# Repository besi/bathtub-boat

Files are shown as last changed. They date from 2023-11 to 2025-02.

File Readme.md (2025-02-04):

Bath tub boat
==============

Measure the temperature of your bath tub.
Video: https://vimeo.com/909430078

## Hardware 

### Version 2
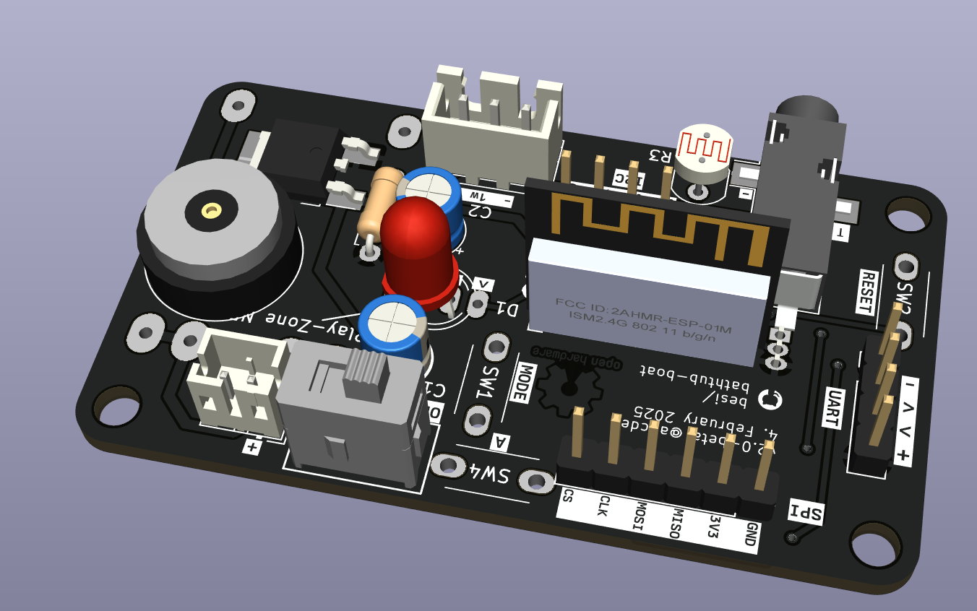
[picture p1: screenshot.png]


### Version 1
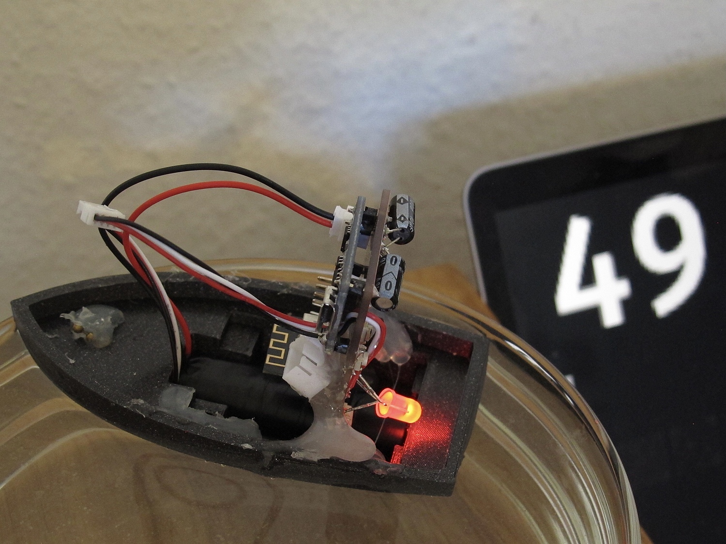
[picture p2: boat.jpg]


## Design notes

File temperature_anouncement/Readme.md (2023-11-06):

# Bathtub Temperature Announcement

- I'm in the kitchen
- The bathtub is filling up
- I'll know when the perfect temperature of 42° is reached

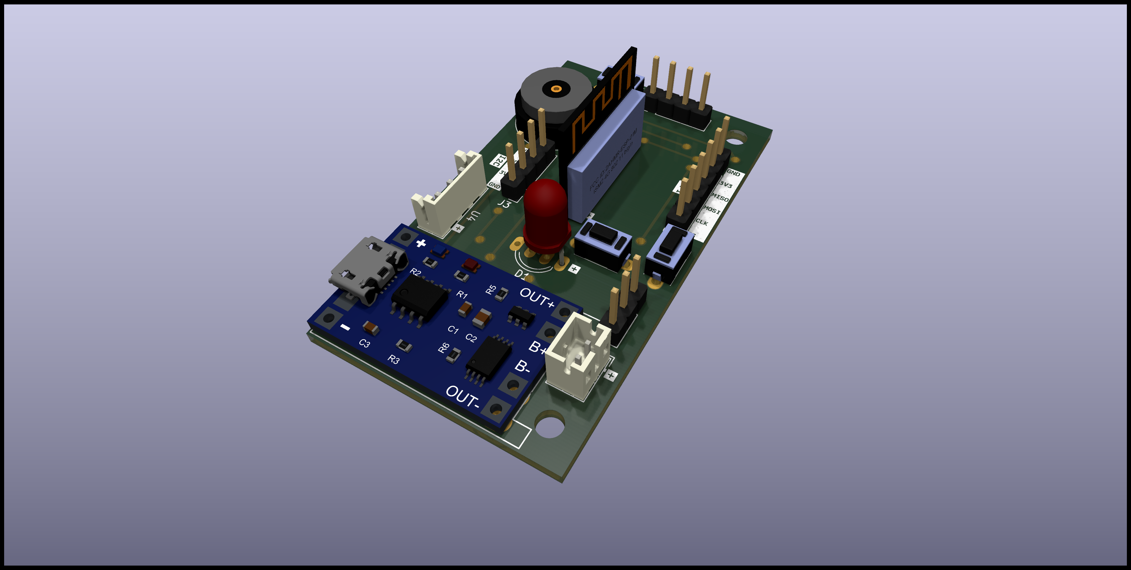
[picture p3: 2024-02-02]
bathtub-boat.png

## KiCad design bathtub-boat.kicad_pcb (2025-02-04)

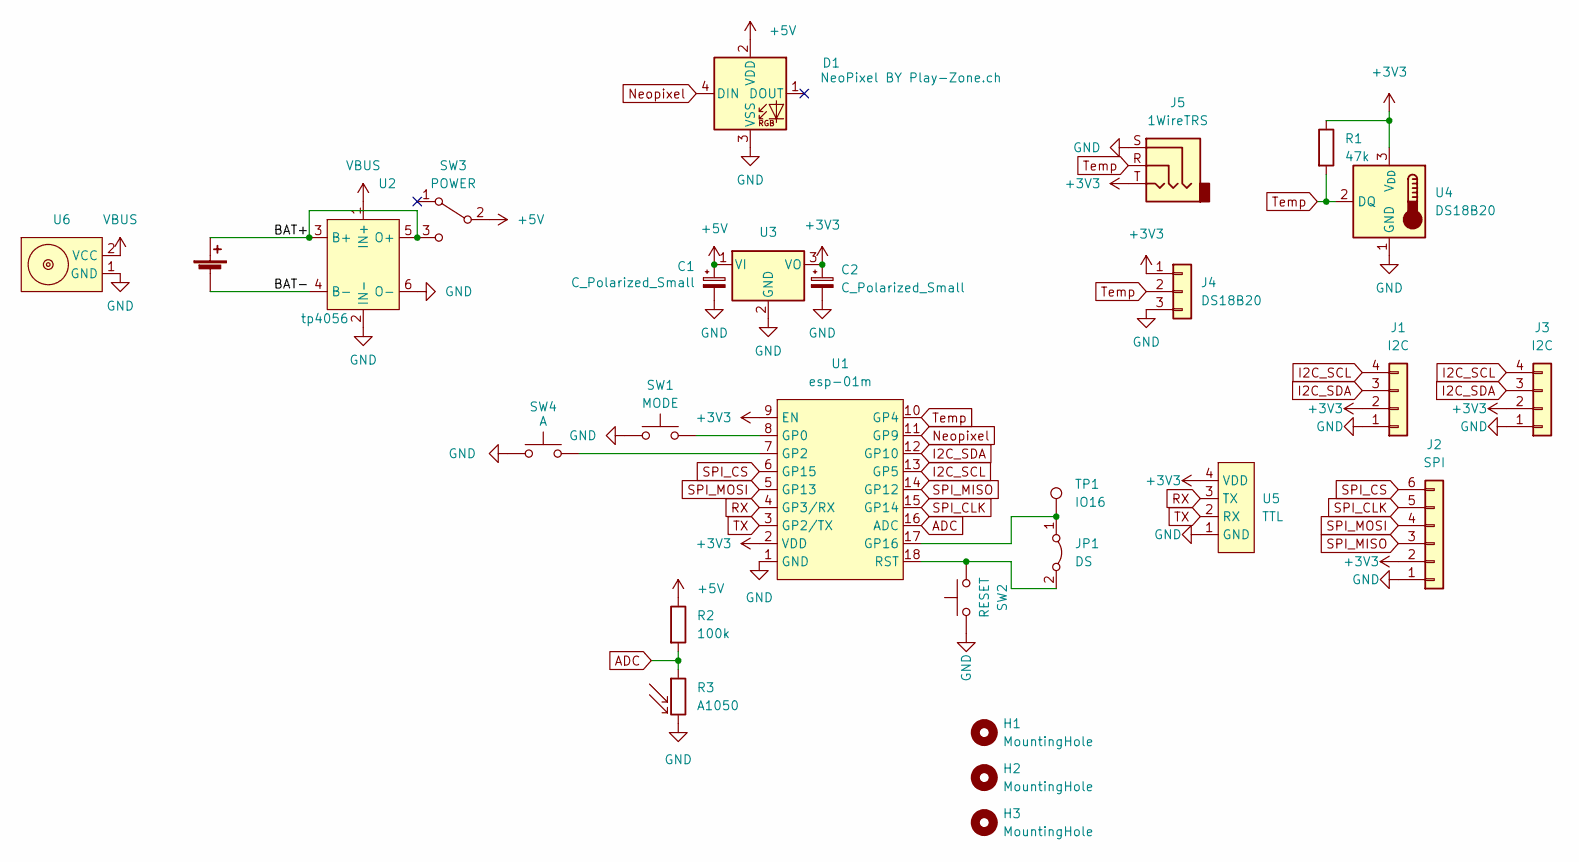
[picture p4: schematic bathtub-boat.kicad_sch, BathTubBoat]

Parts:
BT3: Battery_Cell; JST_PH_B2B-PH-K_1x02_P2.00mm_Vertical
C1, C2: C_Polarized_Small; CP_Radial_D5.0mm_P2.50mm
D1: NeoPixel BY Play-Zone.ch; LED_D5.0mm-4_RGB_Wide_Pins
H1, H2, H3: MountingHole; MountingHole_3.2mm_M3
J1: I2C; JST_SH_SM04B-SRSS-TB_1x04-1MP_P1.00mm_Horizontal
J2: SPI; PinHeader_1x06_P2.54mm_Vertical
J3: I2C; PinHeader_1x04_P2.54mm_Vertical
J4: DS18B20; JST_XH_B3B-XH-A_1x03_P2.50mm_Vertical
J5: 1WireTRS; Jack_3.5mm_CUI_SJ-3523-SMT_Horizontal
JP1: DS; SolderJumper-2_P1.3mm_Bridged_RoundedPad1.0x1.5mm
R1: 47k; R_Axial_DIN0207_L6.3mm_D2.5mm_P7.62mm_Horizontal
R2: 100k; R_Axial_DIN0207_L6.3mm_D2.5mm_P7.62mm_Horizontal
R3: A1050; R_LDR_4.9x4.2mm_P2.54mm_Vertical
SW1: MODE; pts636
SW2: RESET; pts636
SW3: POWER; as12ap
SW4: A; pts636
TP1: IO16; TestPoint_Pad_D1.0mm
U1: esp-01m
U2: tp4056
U3: UA78M33_TO252; TO-252-2
U4: DS18B20; TO-92_Inline
U5: TTL; PinHeader_1x04_P2.54mm_Vertical
U6: magnetic-charger

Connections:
+3V3: C2.1, J1.2, J2.2, J3.2, J4.1, J5.T, R1.1, U1.2 (VDD), U1.9 (EN), U3.3 (VO), U4.3 (V_{DD}), U5.4 (VDD)
+5V: C1.1, D1.2 (VDD), R2.1, SW3.2 (B), U3.1 (VI)
/BAT+: BT3.1 (+), SW3.3 (C), U2.3 (B+), U2.5 (O+)
/BAT-: BT3.2 (-), U2.4 (B-)
ADC: R2.2, R3.1, U1.16 (ADC)
GND: C1.2, C2.2, D1.3 (VSS), J1.1, J2.1, J3.1, J4.3, J5.S, R3.2, SW1.1, SW2.1, SW4.1, U1.1 (GND), U2.2 (IN-), U2.6 (O-), U3.2 (GND), U4.1 (GND), U5.1 (GND), U6.1 (GND)
I2C_SCL: J1.4, J3.4, U1.13 (GP5)
I2C_SDA: J1.3, J3.3, U1.12 (GP10)
Neopixel: D1.4 (DIN), U1.11 (GP9)
unnamed: JP1.1 (A), TP1.1, U1.17 (GP16)
unnamed: JP1.2 (B), SW2.2, U1.18 (RST)
unnamed: SW1.2, U1.8 (GP0)
unnamed: SW4.2, U1.7 (GP2)
RX: U1.4 (GP3/RX), U5.3 (TX)
SPI_CLK: J2.5, U1.15 (GP14)
SPI_CS: J2.6, U1.6 (GP15)
SPI_MISO: J2.3, U1.14 (GP12)
SPI_MOSI: J2.4, U1.5 (GP13)
TX: U1.3 (GP2/TX), U5.2 (RX)
Temp: J4.2, J5.R, R1.2, U1.10 (GP4), U4.2 (DQ)
VBUS: U2.1 (IN+), U6.2 (VCC)

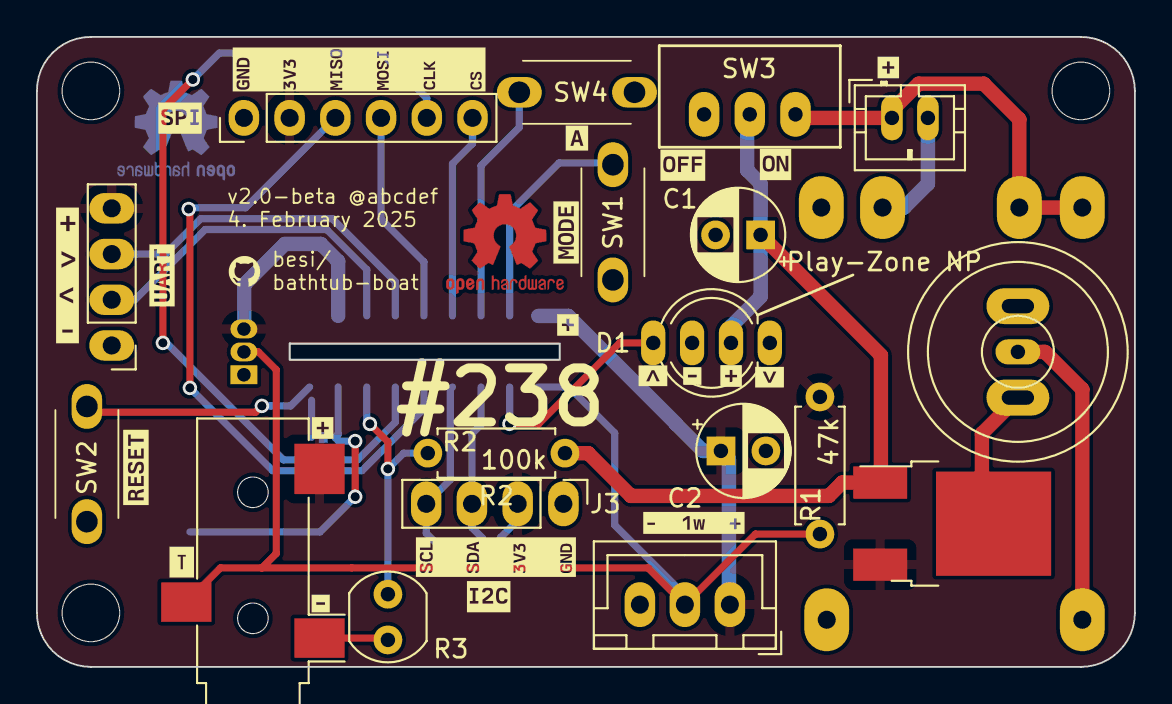
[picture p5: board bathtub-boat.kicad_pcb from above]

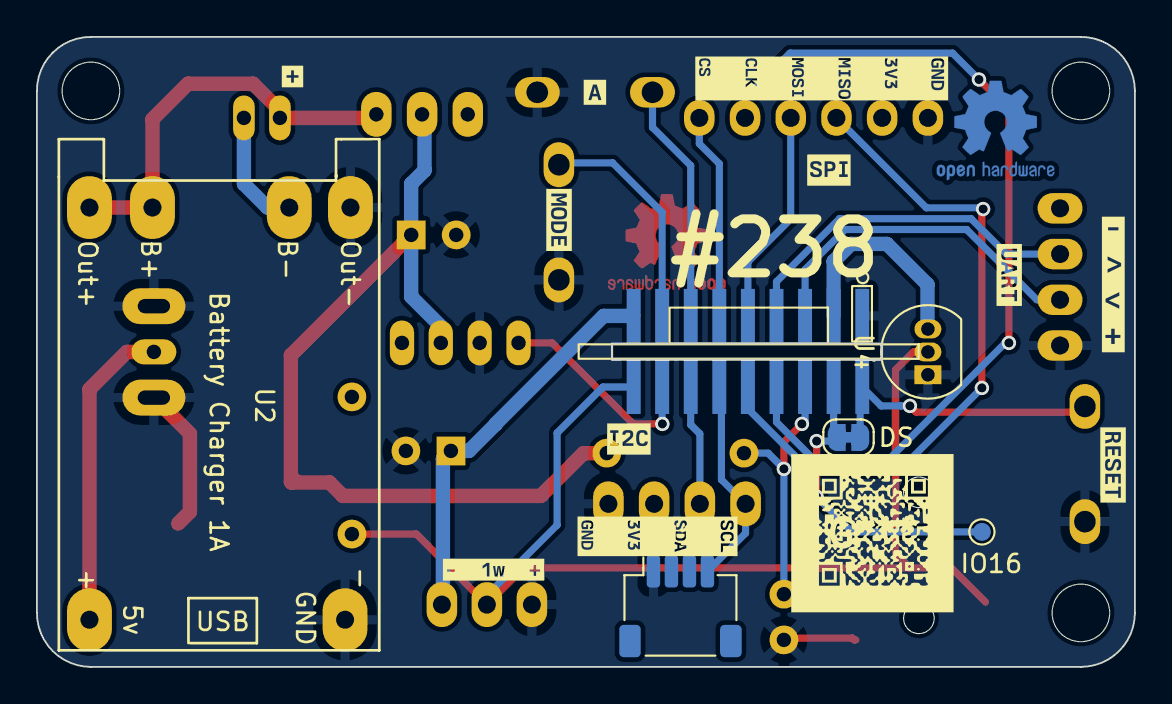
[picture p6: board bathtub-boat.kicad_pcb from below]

Board: 2 copper layers, 61.0 x 35.0 mm, 59 parts (17 on the bottom side), 21 nets.

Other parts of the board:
kibuzzard-65B8C3A2, kibuzzard-65B8C3A2#2: G***; kibuzzard-65B8C3A2
kibuzzard-65B8C65E, kibuzzard-65B8C65E#2: G***; kibuzzard-65B8C65E
kibuzzard-65B8C757, kibuzzard-65B8C757#2: G***; kibuzzard-65B8C757
kibuzzard-65B795B9, kibuzzard-65B795B9#2, kibuzzard-65B795B9#3, kibuzzard-65B795B9#4, kibuzzard-65B795B9#5: G***; kibuzzard-65B795B9
kibuzzard-65B796EF, kibuzzard-65B796EF#2: G***; kibuzzard-65B796EF
kibuzzard-65B796FD, kibuzzard-65B796FD#2: G***; kibuzzard-65B796FD
kibuzzard-65B7959E, kibuzzard-65B7959E#2: G***; kibuzzard-65B7959E
kibuzzard-65B7965E, kibuzzard-65B7965E#2: G***; kibuzzard-65B7965E
kibuzzard-65B79508, kibuzzard-65B79508#2: G***; kibuzzard-65B79508
kibuzzard-65B79597, kibuzzard-65B79597#2: G***; kibuzzard-65B79597
kibuzzard-65B98079: G***; kibuzzard-65B98079
kibuzzard-65B98083: G***; kibuzzard-65B98083
kibuzzard-65D6F389, kibuzzard-65D6F389#2: G***; kibuzzard-65D6F389
kibuzzard-65D7C44D, kibuzzard-65D7C44D#2: G***; kibuzzard-65D7C44D
kibuzzard-67A2929D: G***; kibuzzard-67A2929D
kibuzzard-679F7FF7, kibuzzard-679F7FF7#2: G***; kibuzzard-679F7FF7

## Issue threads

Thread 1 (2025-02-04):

Version 2.0 Checklist

besi, 2025-02-04:
# PCBChecklist

## Idea

## Breadboard
- [x] Write a hardware test script

## Schematic
- [x] Include or add new footprints
- [x] Get all datasheets
- [x] Add project to Git and enable git fow
- [x] Add a Readme.md
- [x] Add testpoints
- [x] Run ERC

## Layout

- [x] Import all components
- [x] Test-upload to JLC to get a feeling for the price
- [x] Remove items that don't need to be in the bom like solder jumpers, mounting holes etc.
- [x] Add missing 3d models (http://grabcad.com)
- [x] Add an image to the Readme
- [x] Add measurements
- [x] Add mounting holes
- [x] Cleanup Silkscreen
- [x] Add a Logo / URL / QRCode / Projectnumber / Date
- [x] Add a beta version label
- [x] Annotate "Exclude from Bom/Positions" as well as "Not in schematic"
- [x] Run DRC
- [x] Write a Pinout to the Readme.md

## Order
- [x] Add a version and date and check in the change
- [x] Add the latest commit and date to the silkscreen and hit the "Production" Plugin (Don't save this Change)

## Post order
- [x] Add a version branch using git flow or git
- [x] Add an new beta-version to the schematics and the pcb

## Sourcing

KubaO, 2025-03-06:
I forked it and did some fixes in my branch: https://github.com/KubaO/bathtub-boat/tree/fixes

All of the traces were removed, and layout was redone.

Closed 2025-03-07.

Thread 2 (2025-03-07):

HW Test 2.0

besi, 2025-03-07:
- [x] LED works
- [x] UART and Charger work
- [x] Onboard One Wire Sensor works
- [ ] OneWire through 3.5mm jack
- [ ] I2C device
- [ ] Button A and B
- [ ] SPI
- [ ] Lightsensor

## Issues

- [ ] The device can't be used without a battery since the tp4056 switches the load off if there is no battery
- [ ] Silkscreen is very small
- [ ] QR Code has some label on top
- [ ] One Wire requires reinforcement
- [ ] Charging indicator would be nice

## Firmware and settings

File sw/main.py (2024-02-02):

import secrets
import time
import ubinascii
import umqttsimple
from umqttsimple import MQTTClient 

import neopixel
np = neopixel.NeoPixel(machine.Pin(10),1) # New Pin 9
#### Careful GRB instead of RGB ###

DELAY = 5
IDEAL = 41
## MQTT
client_id = ubinascii.hexlify(machine.unique_id())
topic_pub = secrets.mqtt.topic
mqtt_server = secrets.mqtt.host
mqtt_port = secrets.mqtt.port
mqtt_user = secrets.mqtt.user
mqtt_password = secrets.mqtt.password

# 1 Wire
import machine
import onewire, ds18x20
from onewire import OneWireError
dat = machine.Pin(9) # New Pin 4
ds = ds18x20.DS18X20(onewire.OneWire(dat))

# If another sensor is plugged in the internal one will be ignored.
internalSensor = bytearray(b'(\xd8)\x95\xf0\x01<D')

def waitForSensors(ds):
    np.fill((10,0,0));np.write()
    sensors = []
    while len(sensors) == 0:
        sensors = ds.scan()
        print('found devices:', sensors)
        if len(sensors) == 0:
            time.sleep(1)
        if len(sensors) > 1:
            print("Ignoring internal sensor")
            sensors.remove(internalSensor)
    np.fill((10,10,10));np.write()
    return sensors

sensors = waitForSensors(ds)

def connect():
  # if you set keepalive value - you have to send something to mqtt server to inform that you are alive in less time than keepalive value of seconds.
  client = MQTTClient(client_id, mqtt_server, mqtt_port, mqtt_user, mqtt_password,keepalive=DELAY * 2)
  client.set_last_will(topic_pub, '{ "status":"offline"} ', retain=False, qos=0)
  client.connect()
  print('Connected to %s MQTT broker' % mqtt_server)
  client.publish(topic_pub, bytes('{"status":"hello"}', 'utf-8'))
  return client


def restart_and_reconnect():
  print('Failed to connect to MQTT broker. Reconnecting...')
  machine.reset()


try:
  print("Connecting to MQTT...")
  client = connect()
except OSError as e:
  restart_and_reconnect()

startup = True

def updateLED(temp):
    (red,green,blue) = (0,0,0)
    green = max((255 - abs(int((IDEAL - temp) * 30))),0)

    if temp < IDEAL:
        blue = max((int((IDEAL - temp) * 30)),0) 
    else:
        red = min((int((temp - IDEAL) * 60)),255)

    d = 15 # dim the leds by this factor
    np.fill((int(green/d), int(red/d), int(blue/d)))
    np.write()


while True:
  try:
    ds.convert_temp()
    for sensor in sensors:
        t = ds.read_temp(sensor)
        if startup and (int(t) == 85 or int(t) == 0 or int(t) == 25):
            print(f"Ignoring {int(t)} degrees at startup")
        print("Temperature: %f" % t)
        updateLED(t)
        client.publish(topic_pub, bytes('{"temp":%f}'% t, 'utf-8'))
        startup = False
    time.sleep(DELAY)
  except OneWireError as e:
      print("Sensor lost")
      sensors =  waitForSensors(ds)
  except OSError as e:
    restart_and_reconnect()
  except Exception as e:
      print("Sensor lost")
      sensors =  waitForSensors(ds)

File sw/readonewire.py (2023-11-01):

import time
import machine
import onewire, ds18x20

# the device is on GPIO12
dat = machine.Pin(33)

# create the onewire object
ds = ds18x20.DS18X20(onewire.OneWire(dat))

# scan for devices on the bus
roms = ds.scan()
print('found devices:', roms)

# loop 10 times and print all temperatures
while True:
    t = time.time()%100
    ds.convert_temp()
    time.sleep_ms(1000)
    for rom in roms:
            print('temp %s' % ds.read_temp(rom))

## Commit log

2023-11-01 Send the temperature over MQTT
2023-11-06 Bathtub temperature announcement
2023-11-06 Properly announce the temperature and startup the service at boot
2023-11-11 Only announce the temperature if the value changed to prevent spamming
2023-11-26 Prevent 85 degrees at startup
    [main.py]
2023-11-26 Log the temperature
2023-12-21 Initial pcb commit
    [bathtub-boat.kicad_pcb, bathtub-boat.kicad_sch]
2023-12-22 Add initial pcb
    [bathtub-boat.kicad_pcb, bathtub-boat.kicad_sch]
2024-01-04 Add components
    [bathtub-boat.kicad_pcb, bathtub-boat.kicad_sch]
2024-01-05 Prepare for milling
    [bathtub-boat.kicad_pcb]
2024-01-22 Closer layout
    [bathtub-boat.kicad_pcb]
2024-01-22 Add readme and fix 3d model of lipo charger
    [bathtub-boat.kicad_pcb]
2024-01-22 Prepare the pcb for next iteration
    [bathtub-boat.kicad_pcb, bathtub-boat.kicad_sch]
2024-01-24 Minor changes to board, reflect tp4056 connections, todos for upcoming version
    [bathtub-boat.kicad_pcb, bathtub-boat.kicad_sch]
2024-01-24 Using the ESP8266 pcb and change the pin from 33 to 9
2024-01-30 New PCB version 2.0
    [bathtub-boat.kicad_pcb, bathtub-boat.kicad_sch]
2024-01-30 Updated software that waits for sensors
2024-01-30 Add power switch
    [bathtub-boat.kicad_pcb, bathtub-boat.kicad_sch]
2024-02-02 Ignore internal sensor if another is plugged in
2024-02-02 Fix last will message
    [main.py]
2024-02-02 Add LED indicator
2024-02-02 react to sensor changes and reset the announcement on new sensors
2024-02-03 Remove debuggin print statements
2024-02-22 Production ready
    [bathtub-boat.kicad_pcb]
2024-02-22 Add pullup resistor for optional parasitic power
    [bathtub-boat.kicad_pcb, bathtub-boat.kicad_sch]
2024-02-22 Update Silkscreen
    [bathtub-boat.kicad_pcb]
2025-02-02 Add a top copper pour
    [bathtub-boat.kicad_pcb, bathtub-boat.kicad_sch]
2025-02-02 Round corners some silkscreen cleanup and a TRS Plug for the 1Wire connection
    [bathtub-boat.kicad_pcb, bathtub-boat.kicad_sch]
2025-02-04 Use special Play-Zone NeoPixel which has a different layout
    [bathtub-boat.kicad_pcb, bathtub-boat.kicad_sch]
2025-02-04 Final preparations for production
    [bathtub-boat.kicad_pcb, bathtub-boat.kicad_sch]
2025-02-04 Add measurements
    [bathtub-boat.kicad_pcb]
2025-02-04 Add a DS18B20 that is facing downwards in the center for under water placement
    [bathtub-boat.kicad_pcb, bathtub-boat.kicad_sch]
2025-02-04 Change resistors, improve silkscreen and add OSHW logo
    [bathtub-boat.kicad_pcb, bathtub-boat.kicad_sch]
2025-02-04 Final tweaks prior to production
    [bathtub-boat.kicad_pcb, bathtub-boat.kicad_sch]
2025-02-04 Add solder jumper and testpoint for IO16
    [bathtub-boat.kicad_pcb, bathtub-boat.kicad_sch]
